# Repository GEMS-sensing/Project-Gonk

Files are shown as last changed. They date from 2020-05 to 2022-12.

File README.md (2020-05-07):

# Project-Gonk
Hardware files for battery holder systems with integrated protection 

## Notation
#### Example: 18650 1S3P 

18650 -> Model of battery used <br>
1S -> The number of cells in <b>series</b><br>
3P -> The number of cells in <b>parallel</b><br>

Output Voltage = SeriesNumber * CellVoltage<br>
Capacity = ParallelNumber * CellCapacity<br>

## Models
- [18650 1S3P](18650_1S3P)

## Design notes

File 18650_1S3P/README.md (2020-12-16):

# Project-Gonk 
### Battery: 18650 
### Configuration: 1S3P
Battery holder with integrated protection and control

# Usage
1. Toggle switch to "<b>OFF</b>" position
2. Verify battery voltage (Maximum difference between highest and lowest voltage cell should be less than <b>0.2V</b>)
3. Insert batteries into holders (<b>Note polarity markings</b>)
4. Verify polarity - if any of the <b>red indicator lamps</b> are lit, <b>stop!</b> Remove offending batteries and fix polarity before proceeding
5. If no red lamps are lit, connect external system to either of the <b>Vout</b> connectors (<b>observe polarity of connector!</b>)
6. Toggle switch to "<b>ON</b>" position when ready to activate 

# Repo Roadmap
#### [Documents](Documents/) 

General document and image storage for repo and README

#### [Hardware](Hardware/)

Current board files (Eagle), Bill of Materials (BoM), and other design documents

#### [Production](Production/)

Contains the various Gerber and pick and place files required to have the Printed Circuit Boards (PCBs) manufactured or populated 

## Overview
* **Type:** Power
* **Interfaces:** Power
* **Release Version:** v0.1

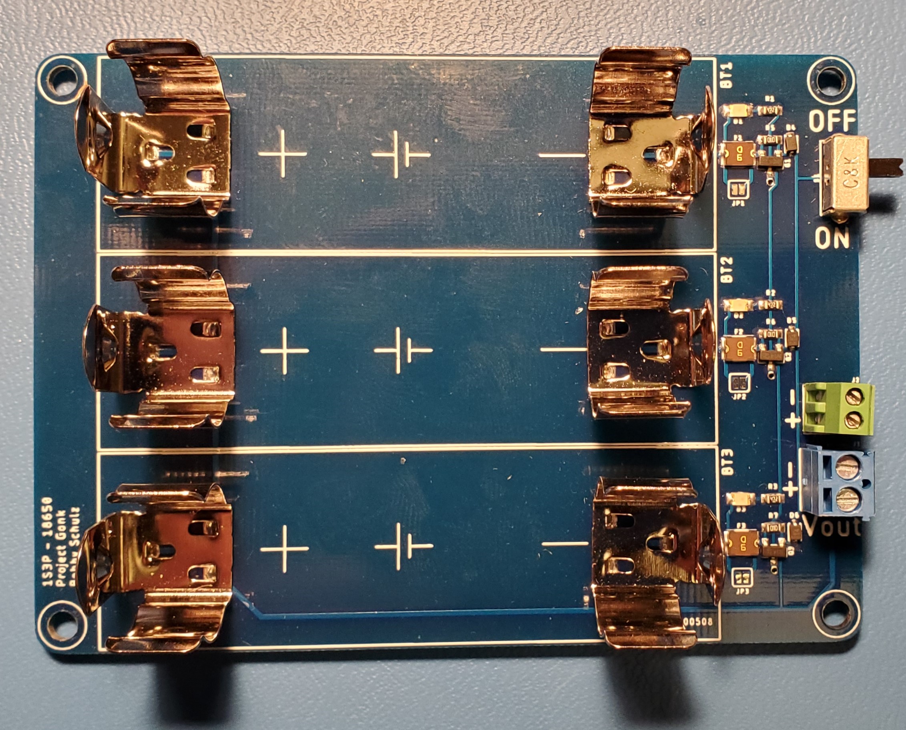
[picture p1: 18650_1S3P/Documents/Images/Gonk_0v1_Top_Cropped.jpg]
Gonk 18650 Parallel v0.1 - Top


<!-- ![Gonk 18650 Parallel v0.1 - Top](Documents/Images/Gonk_0v1_Top.jpg) -->

<!-- ![Gonk 18650 Parallel v0.1 - Bottom](Documents/Images/Gonk_0v1_Bottom.jpg) -->

## Features
### On-Board
* Power switch
* Reverse battery indication
* Poly fuse per battery

### Interface

## Specifications
* **Output Current (Max Constant):** 5.25A
* **Current Per Battery (Max Constant):** 1.75A

## Jumper Settings 

**Configuration Jumpers**
| Jumper | Purpose | Open | Closed | Default | 
| --- | --- | --- | --- | ----- |
| `JP1` | Bypass poly fuse on battery 1 | Short Circuit Protection Enabled | Short Circuit Protection Disabled | Open |  
| `JP2` | Bypass poly fuse on battery 2 | Short Circuit Protection Enabled | Short Circuit Protection Disabled | Open |
| `JP3` | Bypass poly fuse on battery 3 | Short Circuit Protection Enabled | Short Circuit Protection Disabled | Open | 

## Known Issues/Errata

#### None!

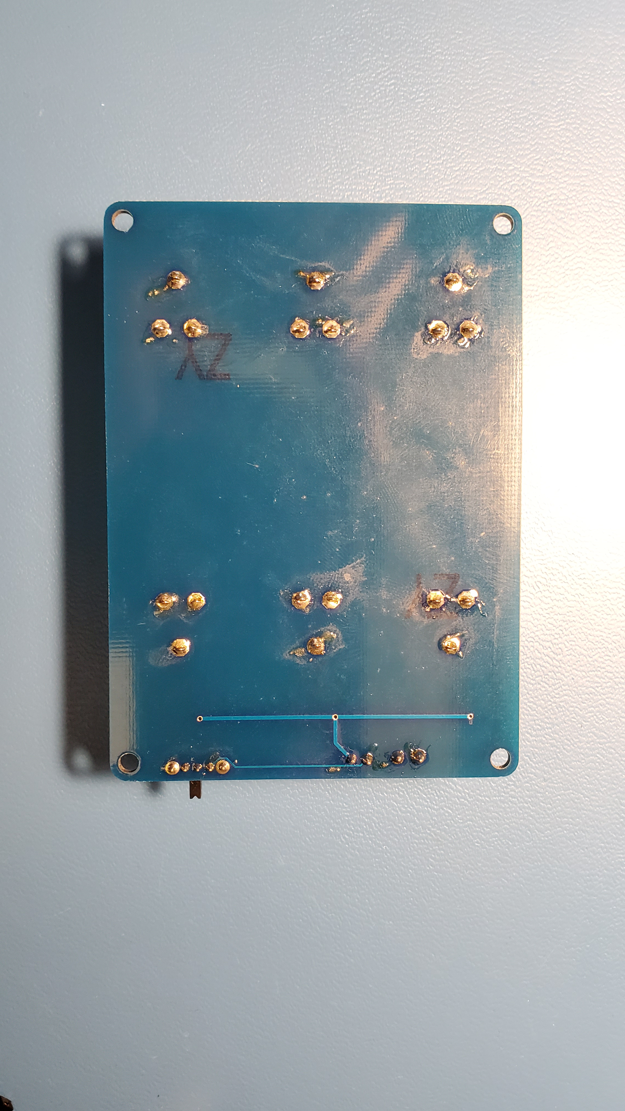
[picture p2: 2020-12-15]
18650_1S3P/Documents/Images/Gonk_0v1_Bottom.jpg

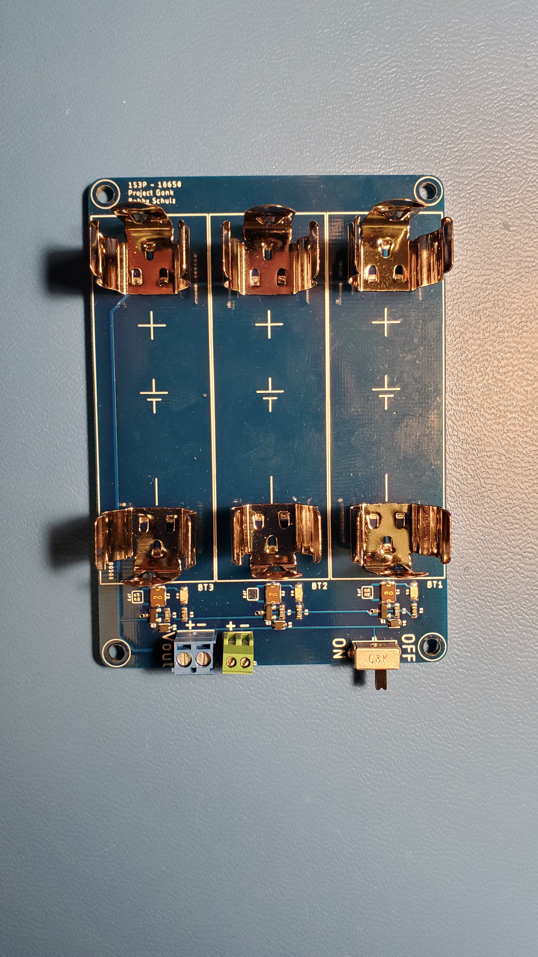
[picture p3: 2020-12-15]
18650_1S3P/Documents/Images/Gonk_0v1_Top.jpg

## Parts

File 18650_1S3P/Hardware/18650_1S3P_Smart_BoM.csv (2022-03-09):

Qty | Value | Device | Package | Parts | Description | DIGIKEY | DISP | MF | MOUSER | MPN | VALUE_PART
4 |  | MOUNTING_HOLE2_NP | 2_56 | H1, H2, H3, H4 | Genaric Mechanical Mounting Hole | DNP |  | N/A |  | DNP
2 | 0.1uF | C-EU0.1UFC0603 | C0603 | C4, C7 | CAPACITOR, European symbol | 490-6051-1-ND |  | Murata |  | GCM188R71E104KA57D
1 | 0.47uF | C-EU0.47UFC0603 | C0603 | C5 | CAPACITOR, European symbol | 1276-2083-1-ND |  | Samsung |  | CL10B474KA8NNNC
6 | 100R | R-EU_100R0603 | R0603 | R1, R5, R7, R11, R13, R17 | RESISTOR, European symbol | 311-100HRCT-ND |  | Yageo |  | RC0603FR-07100RL | 100
2 | 100k | R-EU_100KR0603 | R0603 | R24, R25 | RESISTOR, European symbol | 311-100KHRCT-ND |  | Yageo |  | RC0603FR-07100KL | 100k
1 | 10k | R-EU_10KR0603 | R0603 | R28 | RESISTOR, European symbol | 311-10.0KHRCT-ND |  | Yageo |  | RC0603FR-0710KL | 10k
1 | 10m | R-EU_0.01R0805 | R0805 | R19 | RESISTOR, European symbol | CRF0805-FZ-R010ELFCT-ND |  | Bourns |  | CRF0805-FZ-R010ELF
3 | 186501042P_NOSILK | 186501042P_NOSILK | BATT_1042P_NOSILK | BT1, BT2, BT3 | Battery Holder 18650 form factor Variant for with or without circuit protection (length varries depending on this) | 36-1042P-ND |  | Keystone |  | 1042P
4 | 1M | R-EU_1MR0603 | R0603 | R27, R29, R30, R31 | RESISTOR, European symbol | P1.00MHCT-ND |  | Panasonic |  | ERJ-3EKF1004V | 1M
4 | 1k | R-EU_1KR0603 | R0603 | R3, R9, R15, R32 | RESISTOR, European symbol | 311-1KLDCT-ND |  | Yageo |  | AC0603FR-071KL | 1k
4 | 1uF | C-EU1UFC0603 | C0603 | C1, C2, C3, C6 | CAPACITOR, European symbol | 587-1251-1-ND |  | Yaiyo Yuden |  | EMK107BJ105KA-T
3 | 20R | R-EU_20R0603 | R0603 | R4, R10, R16 | RESISTOR, European symbol | 311-20.0HRCT-ND |  | Yageo |  | RC0603FR-0720RL | 20
3 | 2m | R-EU_0.002R0805 | R0805 | R6, R12, R18 | RESISTOR, European symbol | RHM.002AJCT-ND |  | Rohm |  | PMR10EZPFV2L00
4 | 30R | R-EU_30R0603 | R0603 | R20, R21, R22, R23 | RESISTOR, European symbol | 311-30.0HRCT-ND |  | Yageo |  | RC0603FR-0730RL | 30
4 | 330R | R-EU_330R0603 | R0603 | R2, R8, R14, R26 | RESISTOR, European symbol | 311-330HRCT-ND |  | Yageo |  | RC0603FR-07330RL | 330
3 | BQ2980RUG | BQ2980RUG | RUG_S-PQFP-N8 | U1, U2, U3 | BQ2980 - Voltage, Current, Temperature Protectors with an Integrated High-Side NFET (BMS) | 296-47578-1-ND |  | TI | 595-BQ298000RUGT | BQ298000RUGT
3 | BUTTON6X6_TH | BUTTON6X6_TH | SWITCH_6MM_TH | S1, S2, S3 | Genaric SPST Push button | 450-1650-ND |  | TE Connectivity |  | 1825910-6
1 | CONN_3MICROFIT_RT | CONN_3MICROFIT_RT | 1X3_MICROFIT_RT | J1 | Genaric 3 terminal header | WM1861-ND |  | Molex |  | 0436500300
3 | DIODE_SCHOTTKYSOD-323 | DIODE_SCHOTTKYSOD-323 | SOD323-R | D1, D2, D3 | Generic Shottky Diode | BAT54WS-FDICT-ND |  | Diodes Inc |  | BAT54WS-7-F
1 | GEMS_POWER_PLUGOUTPUT | GEMS_POWER_PLUGOUTPUT | 2X3_MICROFIT_RT | J2 | Power Plug For GEMS Based SystemsBoth Input and Output versions | WM1815-ND | Output | Molex |  | 0430450600
5 | LED1206_BOTTOM | LED1206_BOTTOM | LED_1206_BOTTOM | D4, D5, D6, D7, D8 | Genaric LED
1 | MAX17263 | MAX17263 | DFN_14_3X3 | U4 | MAX17263 - Single/Multi-Cell Fuel Gauge with Integrated LED Control | 175-MAX17263LETD+TCT-ND |  | Maxim |  | MAX17263LETD+T
6 | MOSFET-NCH-AON7522E | MOSFET-NCH-AON7522E | DFN3X3A_8L_EP1_P | Q1, Q2, Q3, Q4, Q5, Q6 | N-channel MOSFETs | 785-1505-1-ND |  | Alpha & Omega |  | AON7522E
2 | MOSFET_PCH-DMP2008 | MOSFET_PCH-DMP2008 | POWERDI3333-8 | Q7, Q8 | P-channel MOSFETs
1 | SPDTOS1020_RT | SPDTOS1020_RT | OS102011MA1QN1 | S4 | Genaric SPDT switch | CKN9559-ND |  | C&K |  | OS102011MA1QN1
1 | TLV3691DCK | TLV3691DCK | DCK_R-PDSO-G5 | U5 | TLV3691 - Nanopower Analog Comparator | 296-37910-1-ND |  | TI |  | TLV3691IDCKR

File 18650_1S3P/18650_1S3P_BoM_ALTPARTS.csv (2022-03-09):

Qty | Value | Device | Package | Parts | Description | DIGIKEY | MF | MPN | VALUE | VALUE_PART
1 |  | CONN_022.54_SCREW_ROUND | 1X02_2.54_SCREWTERM_ROUND | J2 | Genaric 2 terminal header | ED10561-ND | OnShore | OSTVN02A150
1 |  | CONN_023.5MM_ROUND_RESTRICT | SCREWTERMINAL-3.5MM-2_ROUND_RESTRICT | J1 | Genaric 2 terminal header | ED2635-ND | On Shore | OSTTE020161
4 |  | MOUNTING_HOLE4_NP | 4_40 | H1, H2, H3, H4 | Genaric Mechanical Mounting Hole | DNP | N/A | DNP
3 | 1.75A | PPTC1.75A1210 | 1210_BOURNS | F1, F2, F3 | Bel Fuse PPTC | MF-USMF175X-2CT-ND | Bourns | MF-USMF175X-2
3 | 100k | R-EU_100KR0603 | R0603 | R5, R6, R7 | RESISTOR, European symbol | 311-100KHRCT-ND | Yageo | RC0603FR-07100KL |  | 100k
3 | 18650NO_PROTEC | 18650NO_PROTEC | BATT_18650_CLIP | BT1, BT2, BT3 | Battery Holder 18650 form factor Variant for with or without circuit protection (length varries depending on this) | 36-54-ND | Keystone | 54
3 | BAS16WX | DIODESOD-323 | SOD323-R | D4, D5, D6 | Genaric Diode | BAS16WXTPMSDKR-ND | Micro Semi | BAS16WX-TP
3 | 4.7k | R-EU_4.7KR0603 | R0603 | R1, R2, R3 | RESISTOR, European symbol | 311-4.70KHRCT-ND | Yageo | RC0603FR-074K7L |  | 4.7k
3 | DMG3406 | MOSFET-NCH-DMG3406L | SOT23-3 | Q1, Q2, Q3 | N-channel MOSFETs | DMG3406L-13DICT-ND | Diodes Incorporated | DMG3406L-13 | DMG3406
3 | JUMPER-SMT_2_NO_SILK | JUMPER-SMT_2_NO_SILK | SMT-JUMPER_2_NO_SILK | JP1, JP2, JP3 | Normally open jumper | N/A | N/A | DNP
3 | LED0805 | LED0805 | LED_0805 | D1, D2, D3 | Genaric LED | 1497-XZMDK54W-4DKR-ND | SunLED | XZMDK54W-4
1 | SPDTOS1020_RT | SPDTOS1020_RT | OS102011MA1QN1 | S1 | Genaric SPDT switch | CKN9559-ND | C&K | OS102011MA1QN1

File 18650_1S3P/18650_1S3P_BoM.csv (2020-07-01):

Qty | Value | Device | Package | Parts | Description | DIGIKEY | MF | MPN | VALUE | VALUE_PART
1 |  | CONN_022.54_SCREW_ROUND | 1X02_2.54_SCREWTERM_ROUND | J2 | Genaric 2 terminal header | ED10561-ND | OnShore | OSTVN02A150
1 |  | CONN_023.5MM_ROUND_RESTRICT | SCREWTERMINAL-3.5MM-2_ROUND_RESTRICT | J1 | Genaric 2 terminal header | ED2635-ND | On Shore | OSTTE020161
4 |  | MOUNTING_HOLE4_NP | 4_40 | H1, H2, H3, H4 | Genaric Mechanical Mounting Hole | DNP | N/A | DNP
3 | 1.75A | PPTC1.75A1210 | 1210_BOURNS | F1, F2, F3 | Bel Fuse PPTC | MF-USMF175X-2CT-ND | Bourns | MF-USMF175X-2
3 | 100k | R-EU_100KR0603 | R0603 | R5, R6, R7 | RESISTOR, European symbol | 311-100KHRCT-ND | Yageo | RC0603FR-07100KL |  | 100k
3 | 18650NO_PROTEC | 18650NO_PROTEC | BATT_18650_CLIP | BT1, BT2, BT3 | Battery Holder 18650 form factor Variant for with or without circuit protection (length varries depending on this) | 36-54-ND | Keystone | 54
3 | 1N4148 | DIODESOD-323 | SOD323-R | D4, D5, D6 | Genaric Diode | 1N4148WS-FDICT-ND | Diodes Inc | 1N4148WS-7-F
3 | 4.7k | R-EU_4.7KR0603 | R0603 | R1, R2, R3 | RESISTOR, European symbol | 311-4.70KHRCT-ND | Yageo | RC0603FR-074K7L |  | 4.7k
3 | DMG3404 | MOSFET-NCH-DMG3404L | SOT23-3 | Q1, Q2, Q3 | N-channel MOSFETs | DMG3404L-7DICT-ND | Diodes Incorporated | DMG3404L-7 | DMG3404
3 | JUMPER-SMT_2_NO_SILK | JUMPER-SMT_2_NO_SILK | SMT-JUMPER_2_NO_SILK | JP1, JP2, JP3 | Normally open jumper
3 | LED0805 | LED0805 | LED_0805 | D1, D2, D3 | Genaric LED | 475-1278-1-ND | OSRAM | LS R976-NR-1
1 | SPDTOS1020_RT | SPDTOS1020_RT | OS102011MA1QN1 | S1 | Genaric SPDT switch | CKN9559-ND | C&K | OS102011MA1QN1

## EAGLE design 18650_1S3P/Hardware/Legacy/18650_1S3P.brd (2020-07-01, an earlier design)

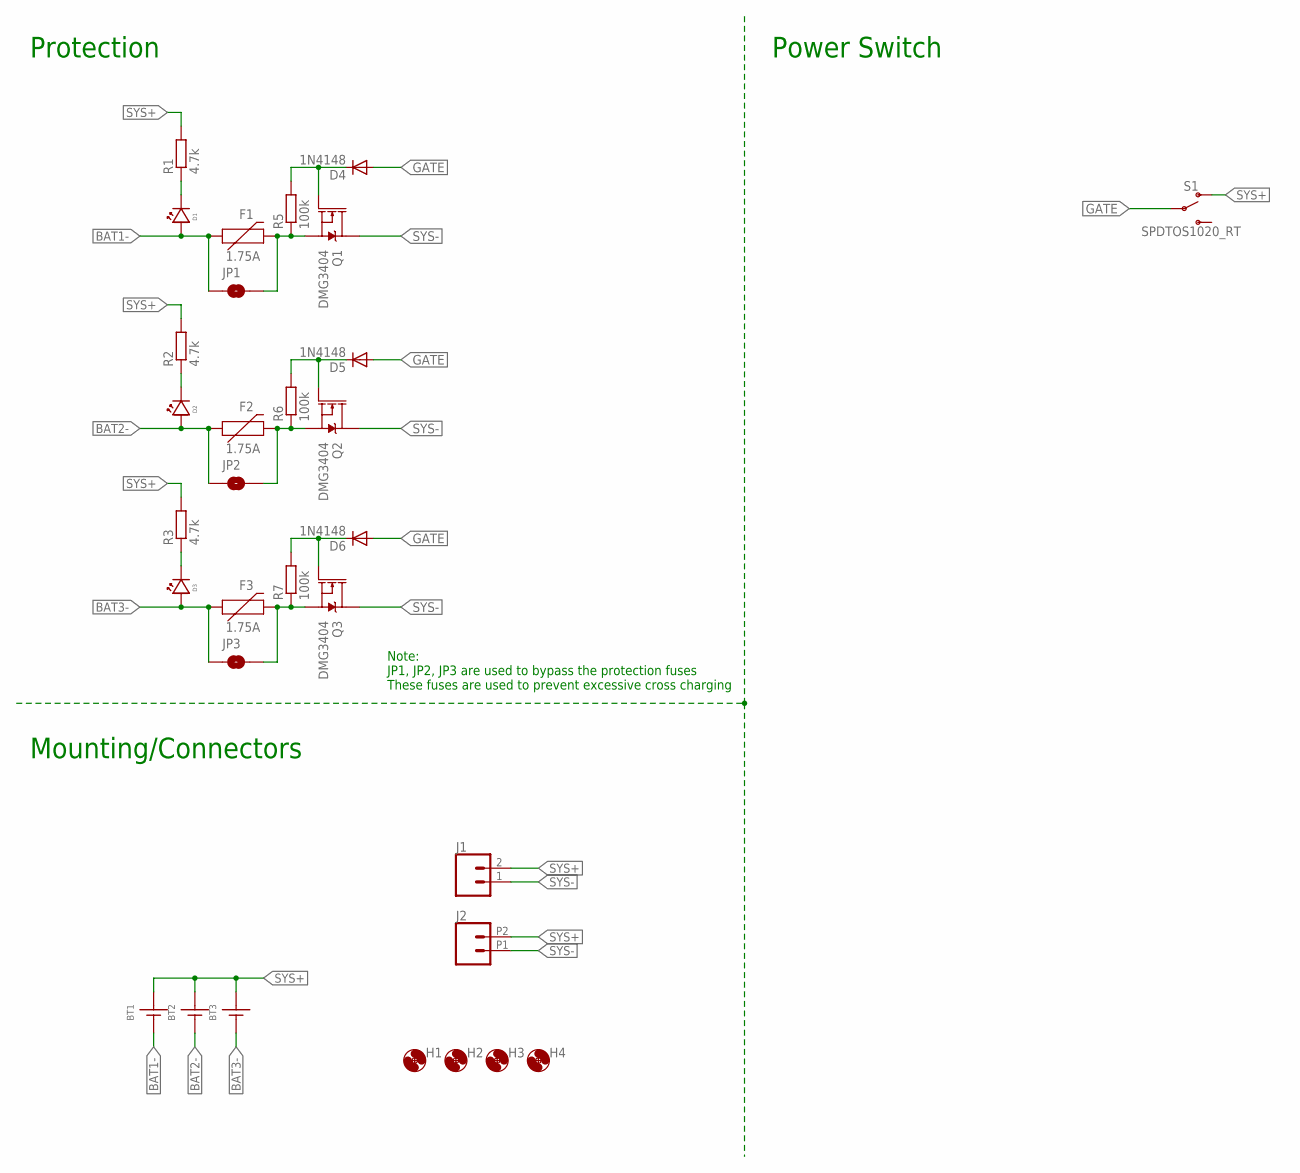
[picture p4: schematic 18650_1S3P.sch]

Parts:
BT1, BT2, BT3: 18650NO_PROTEC; BATT_18650_CLIP
D1, D2, D3: LED0805; LED_0805; MPN LS R976-NR-1; DIGIKEY 475-1278-1-ND
D4, D5, D6: 1N4148; SOD323-R; MPN 1N4148WS-7-F; DIGIKEY 1N4148WS-FDICT-ND
F1, F2, F3: 1.75A; 1210_BOURNS
H1, H2, H3, H4: MOUNTING_HOLE4_NP; 4_40
J1: CONN_023.5MM_ROUND_RESTRICT; SCREWTERMINAL-3.5MM-2_ROUND_RESTRICT
J2: CONN_022.54_SCREW_ROUND; 1X02_2.54_SCREWTERM_ROUND
JP1, JP2, JP3: JUMPER-SMT_2_NO_SILK; SMT-JUMPER_2_NO_SILK
Q1, Q2, Q3: DMG3404; SOT23-3
R1, R2, R3: 4.7k; R0603
R5, R6, R7: 100k; R0603
S1: SPDTOS1020_RT; OS102011MA1QN1

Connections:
BAT1-: BT1.BATT-@1 (-), BT1.BATT-@2 (-), BT1.BATT-@3 (-), D1.ANODE, F1.1, JP1.1
BAT2-: BT2.BATT-@1 (-), BT2.BATT-@2 (-), BT2.BATT-@3 (-), D2.ANODE, F2.1, JP2.1
BAT3-: BT3.BATT-@1 (-), BT3.BATT-@2 (-), BT3.BATT-@3 (-), D3.ANODE, F3.1, JP3.1
GATE: D4.A, D5.A, D6.A, S1.2
unnamed: D2.CATHODE, R2.1
unnamed: D1.CATHODE, R1.1
unnamed: F1.2, JP1.2, Q1.2 (S), R5.1
unnamed: F2.2, JP2.2, Q2.2 (S), R6.1
unnamed: D3.CATHODE, R3.1
unnamed: F3.2, JP3.2, Q3.2 (S), R7.1
unnamed: D5.C, Q2.1 (G), R6.2
unnamed: D4.C, Q1.1 (G), R5.2
unnamed: D6.C, Q3.1 (G), R7.2
SYS+: BT1.BATT+@1 (+), BT1.BATT+@2 (+), BT1.BATT+@3 (+), BT2.BATT+@1 (+), BT2.BATT+@2 (+), BT2.BATT+@3 (+), BT3.BATT+@1 (+), BT3.BATT+@2 (+), BT3.BATT+@3 (+), J1.2, J2.P2 (2), R1.2, R2.2, R3.2, S1.1 (O)
SYS-: J1.1, J2.P1 (1), Q1.3 (D), Q2.3 (D), Q3.3 (D)

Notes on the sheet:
Mounting/Connectors
Protection
Note: JP1, JP2, JP3 are used to bypass the protection fuses These fuses are used to prevent excessive cross charging
Power Switch

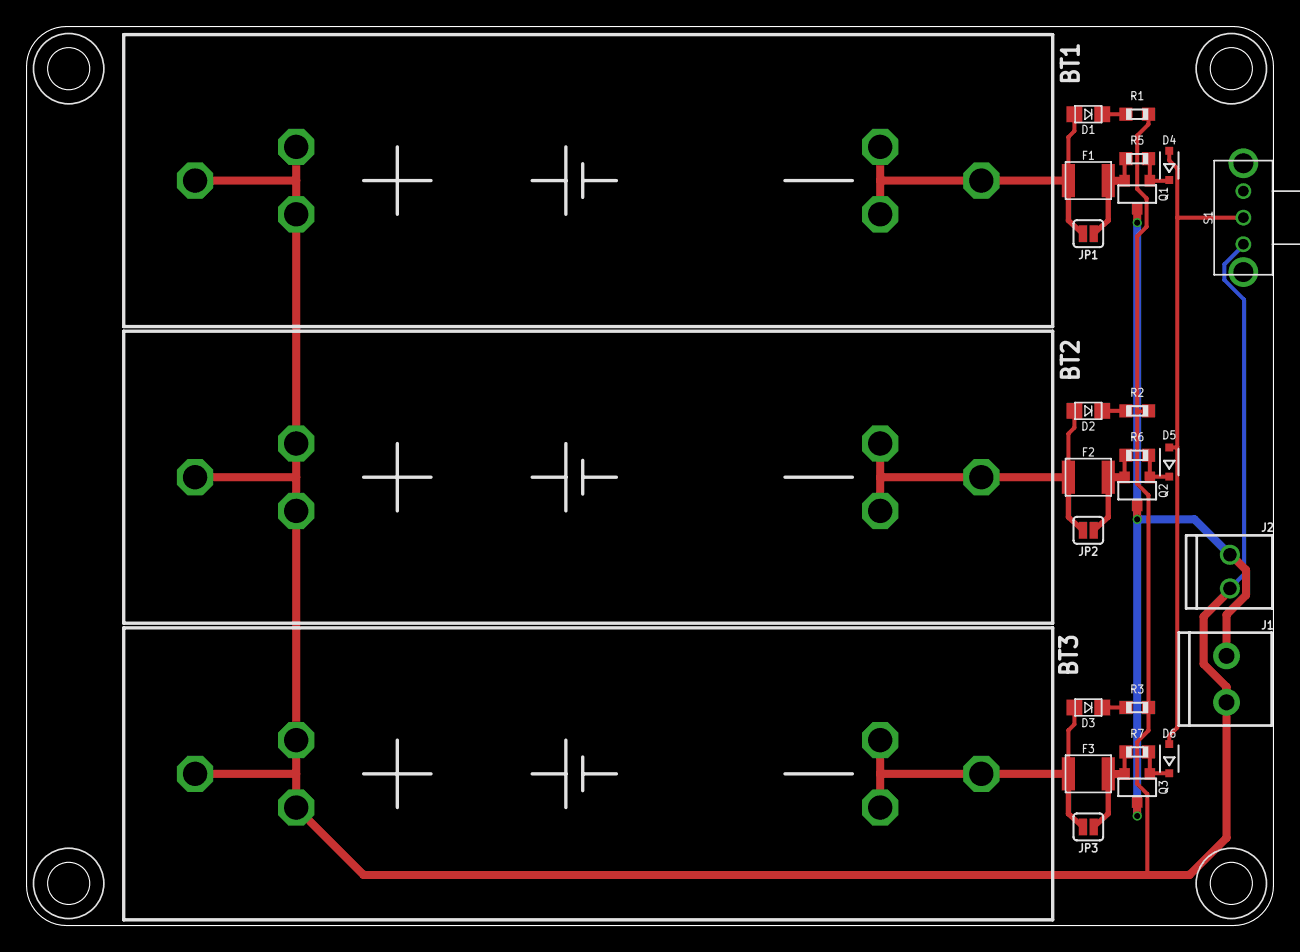
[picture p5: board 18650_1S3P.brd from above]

Board: 2 copper layers, 94.0 x 67.7 mm, 31 parts (0 on the bottom side), 15 nets.

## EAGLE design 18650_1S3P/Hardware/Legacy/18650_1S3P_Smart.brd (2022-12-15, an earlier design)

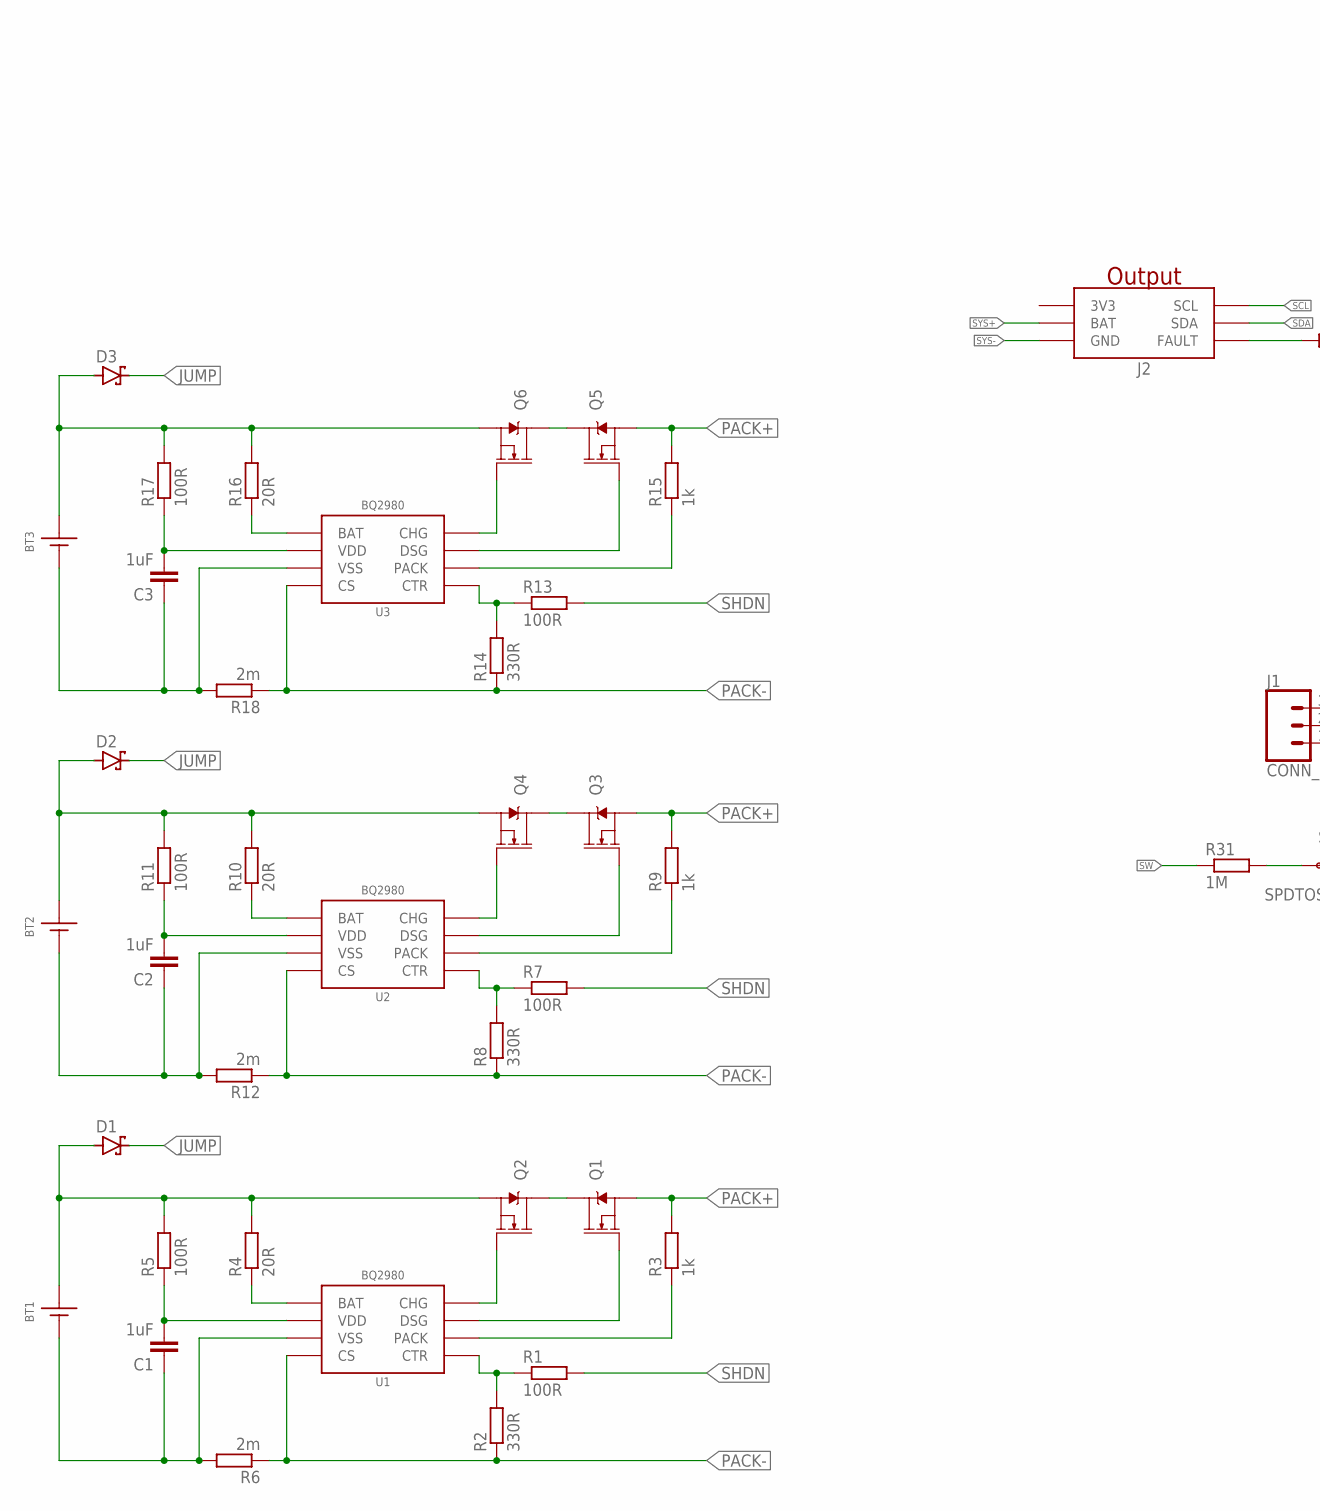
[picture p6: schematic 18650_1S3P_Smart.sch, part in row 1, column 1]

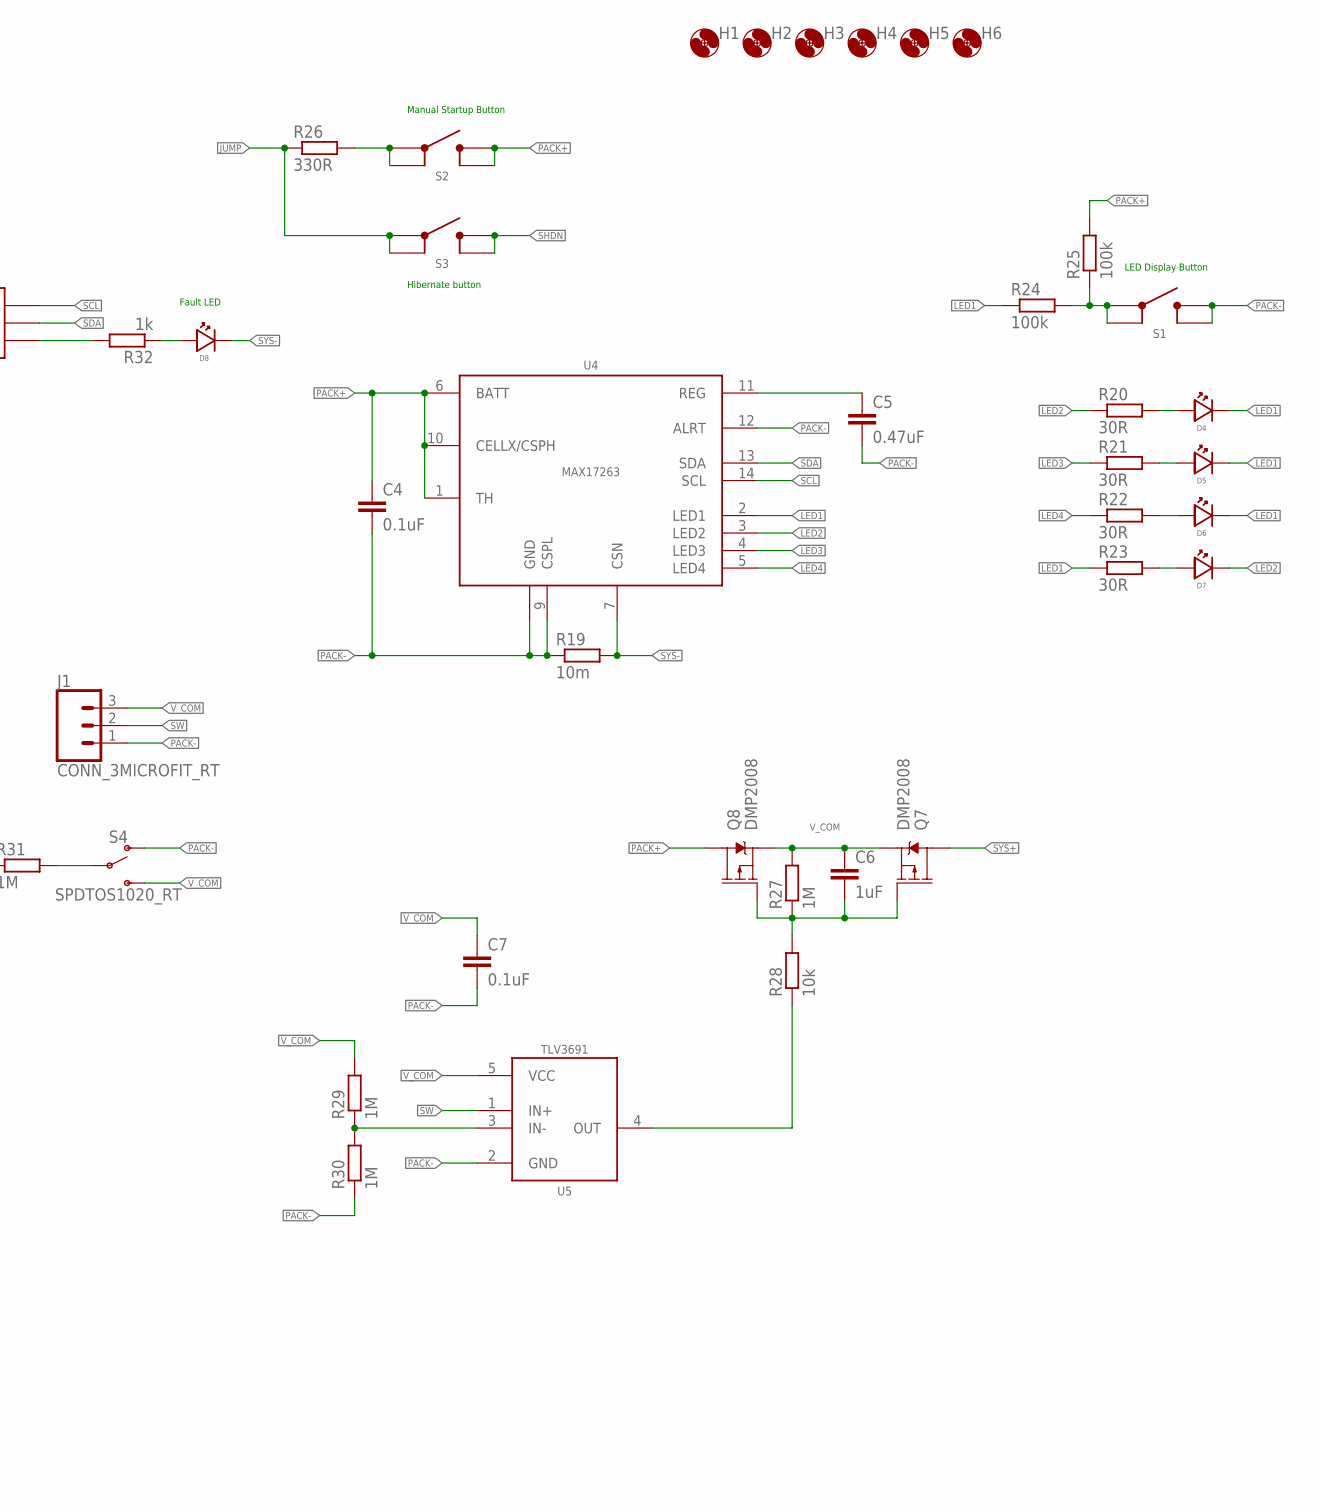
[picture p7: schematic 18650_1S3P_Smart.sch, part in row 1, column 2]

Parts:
BT1, BT2, BT3: 186501042P_NOSILK; BATT_1042P_NOSILK
C1, C2, C3, C6: 1uF; C0603
C4, C7: 0.1uF; C0603
C5: 0.47uF; C0603
D1, D2, D3: DIODE_SCHOTTKYSOD-323; SOD323-R; MPN BAT54WS-7-F; DIGIKEY BAT54WS-FDICT-ND
D4, D5, D6, D7: LED1206_BOTTOM; LED_1206_BOTTOM; MPN LTST-C230KGKT; DIGIKEY 160-1456-1-ND
D8: LED1206_BOTTOM; LED_1206_BOTTOM; MPN LTST-C230KRKT; DIGIKEY 160-1457-1-ND
H1, H2, H3, H4, H5, H6: MOUNTING_HOLE4_NP; 4_40
J1: CONN_3MICROFIT_RT; 1X3_MICROFIT_RT
J2: GEMS_POWER_PLUGOUTPUT; 2X3_MICROFIT_RT
Q1, Q2, Q3, Q4, Q5, Q6: AON7522E; DFN3X3A_8L_EP1_P
Q7, Q8: DMP2008; POWERDI3333-8
R1, R5, R7, R11, R13, R17: 100R; R0603
R2, R8, R14, R26: 330R; R0603
R3, R9, R15, R32: 1k; R0603
R4, R10, R16: 20R; R0603
R6, R12, R18: 2m; R0805
R19: 10m; R0805
R20, R21, R22, R23: 30R; R0603
R24, R25: 100k; R0603
R27, R29, R30, R31: 1M; R0603
R28: 10k; R0603
S1, S2, S3: BUTTON6X6_TH; SWITCH_6MM_TH
S4: SPDTOS1020_RT; OS102011MA1QN1
U1, U2, U3: BQ2980RUG; RUG_S-PQFP-N8
U4: MAX17263; DFN_14_3X3
U5: TLV3691DCK; DCK_R-PDSO-G5

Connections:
3V3: J2.5 (3V3)
JUMP: D1.C, D2.C, D3.C, R26.1, S3.1, S3.2
LED1: D4.CATHODE, D5.CATHODE, D6.CATHODE, R23.1, R24.1, U4.2 (LED1)
LED2: D7.CATHODE, R20.1, U4.3 (LED2)
LED3: R21.1, U4.4 (LED3)
LED4: R22.1, U4.5 (LED4)
unnamed: Q1.D, Q2.D
unnamed: Q2.G, U1.8 (CHG)
unnamed: Q1.G, U1.7 (DSG)
unnamed: R1.1, R2.2, U1.5 (CTR)
unnamed: R3.1, U1.6 (PACK)
unnamed: BT1.BATT+ (+), D1.A, Q2.S@1 (S), Q2.S@2 (S), Q2.S@3 (S), R4.2, R5.2
unnamed: C1.2, R5.1, U1.2 (VDD)
unnamed: R4.1, U1.1 (BAT)
unnamed: BT1.BATT- (-), C1.1, R6.2, U1.3 (VSS)
unnamed: Q3.D, Q4.D
unnamed: Q4.G, U2.8 (CHG)
unnamed: Q3.G, U2.7 (DSG)
unnamed: R9.1, U2.6 (PACK)
unnamed: R7.1, R8.2, U2.5 (CTR)
unnamed: BT2.BATT+ (+), D2.A, Q4.S@1 (S), Q4.S@2 (S), Q4.S@3 (S), R10.2, R11.2
unnamed: C2.2, R11.1, U2.2 (VDD)
unnamed: R10.1, U2.1 (BAT)
unnamed: BT2.BATT- (-), C2.1, R12.2, U2.3 (VSS)
unnamed: Q5.D, Q6.D
unnamed: Q6.G, U3.8 (CHG)
unnamed: Q5.G, U3.7 (DSG)
unnamed: R15.1, U3.6 (PACK)
unnamed: R13.1, R14.2, U3.5 (CTR)
unnamed: BT3.BATT+ (+), D3.A, Q6.S@1 (S), Q6.S@2 (S), Q6.S@3 (S), R16.2, R17.2
unnamed: C3.2, R17.1, U3.2 (VDD)
unnamed: R16.1, U3.1 (BAT)
unnamed: BT3.BATT- (-), C3.1, R18.2, U3.3 (VSS)
unnamed: D4.ANODE, R20.2
unnamed: D5.ANODE, R21.2
unnamed: D6.ANODE, R22.2
unnamed: D7.ANODE, R23.2
unnamed: R24.2, R25.1, S1.1, S1.2
unnamed: C5.1, U4.11 (REG)
unnamed: R26.2, S2.1, S2.2
unnamed: R31.2, S4.2
unnamed: C6.2, Q7.4 (G), Q8.4 (G), R27.1, R28.2
unnamed: R28.1, U5.4 (OUT)
unnamed: J2.1 (FAULT), R32.2
unnamed: R29.1, R30.2, U5.3 (IN-)
unnamed: D8.ANODE, R32.1
PACK+: C4.1, Q1.S@1 (S), Q1.S@2 (S), Q1.S@3 (S), Q3.S@1 (S), Q3.S@2 (S), Q3.S@3 (S), Q5.S@1 (S), Q5.S@2 (S), Q5.S@3 (S), Q8.EP@1 (D), Q8.EP@2 (D), Q8.EP@3 (D), Q8.EP@4 (D), Q8.EP@5 (D), R3.2, R9.2, R15.2, R25.2, S2.3, S2.4, U4.1 (TH), U4.6 (BATT), U4.10 (CELLX/CSPH)
PACK-: C4.2, C5.2, C7.2, J1.1, R2.1, R6.1, R8.1, R12.1, R14.1, R18.1, R19.1, R30.1, S1.3, S1.4, S4.1 (O), U1.4 (CS), U2.4 (CS), U3.4 (CS), U4.8 (GND), U4.9 (CSPL), U4.12 (ALRT), U4.EP (GND), U5.2 (GND)
SCL: J2.4 (SCL), U4.14 (SCL)
SDA: J2.6 (SDA), U4.13 (SDA)
SHDN: R1.2, R7.2, R13.2, S3.3, S3.4
SW: J1.2, R31.1, U5.1 (IN+)
SYS+: J2.3 (BAT), Q7.EP@1 (D), Q7.EP@2 (D), Q7.EP@3 (D), Q7.EP@4 (D), Q7.EP@5 (D)
SYS-: D8.CATHODE, J2.2 (GND), R19.2, U4.7 (CSN)
V_COM: C6.1, C7.1, J1.3, Q7.1 (S), Q7.2 (S), Q7.3 (S), Q8.1 (S), Q8.2 (S), Q8.3 (S), R27.2, R29.2, S4.3 (S), U5.5 (VCC)

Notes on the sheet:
LED Display Button
Manual Startup Button
Hibernate button
Fault LED

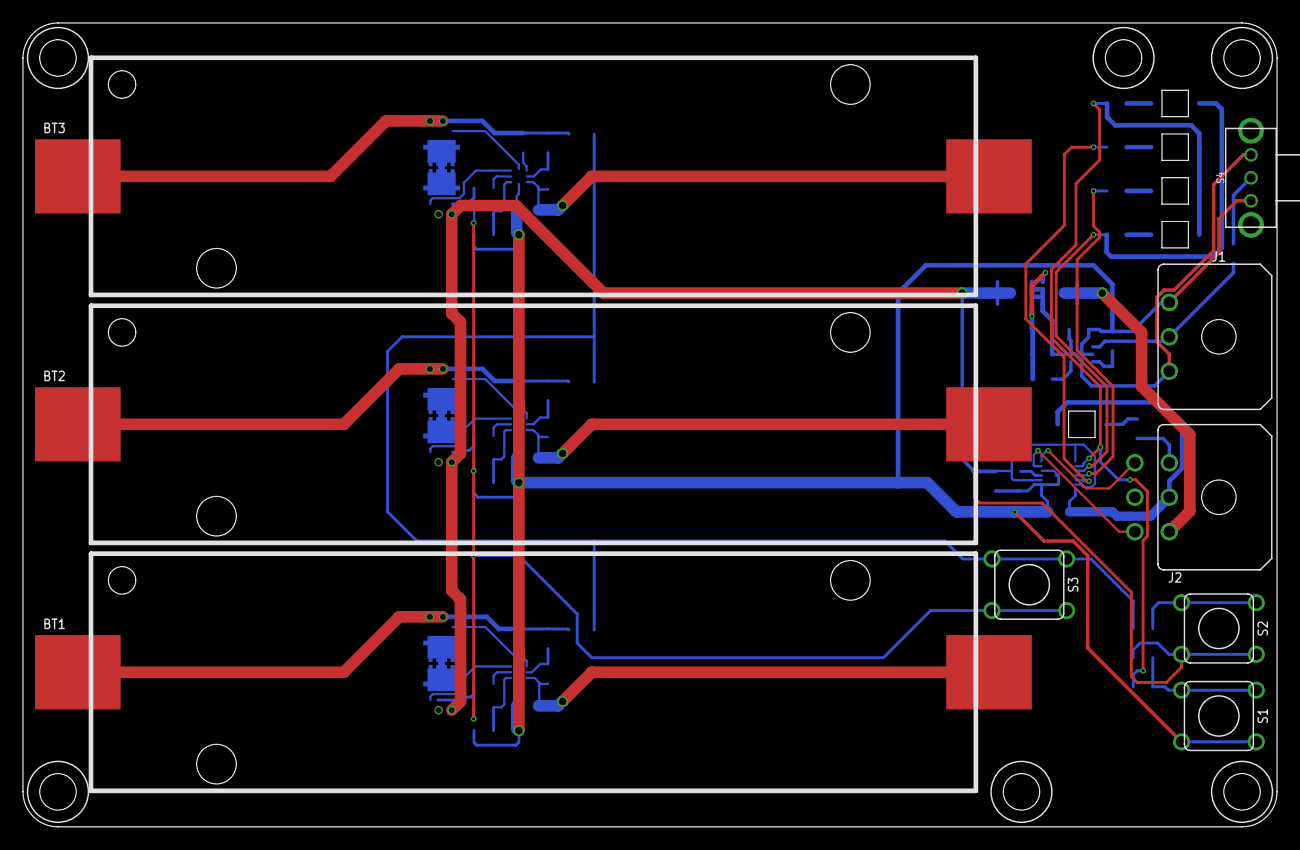
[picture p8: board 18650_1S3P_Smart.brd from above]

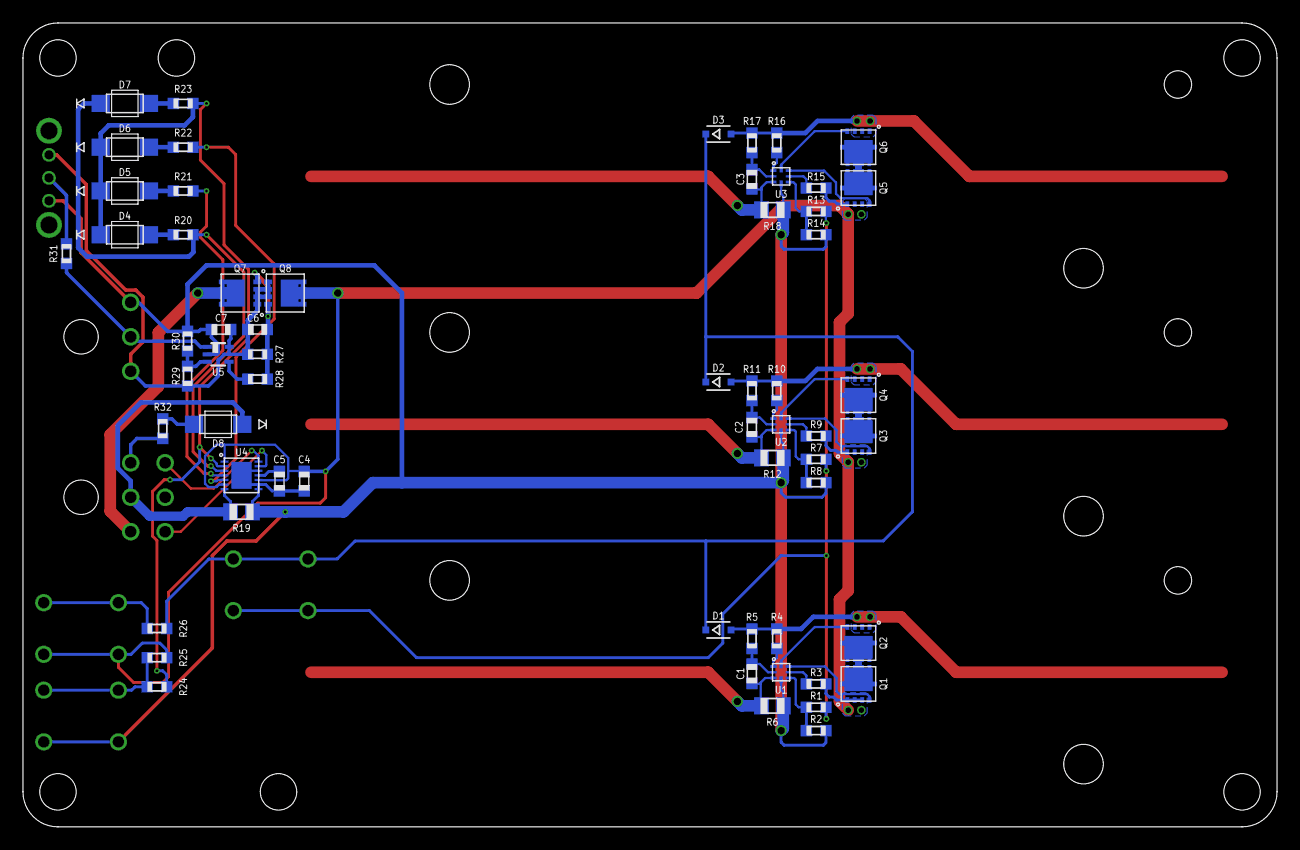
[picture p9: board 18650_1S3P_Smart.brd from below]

Board: 2 copper layers, 109.2 x 70.0 mm, 75 parts (60 on the bottom side), 54 nets.

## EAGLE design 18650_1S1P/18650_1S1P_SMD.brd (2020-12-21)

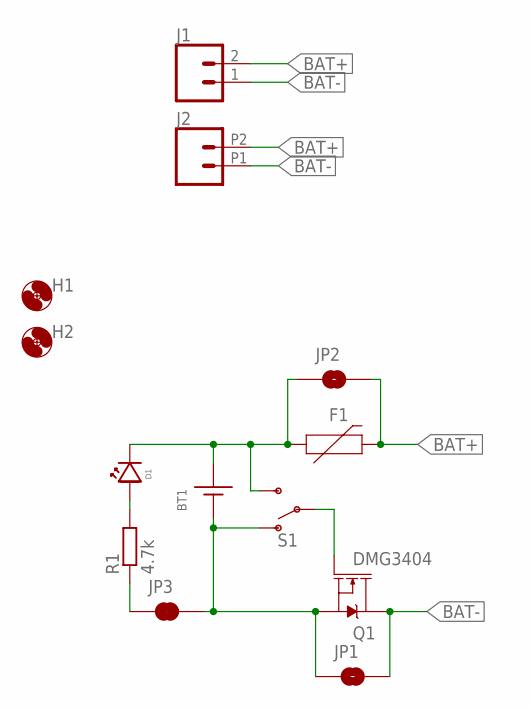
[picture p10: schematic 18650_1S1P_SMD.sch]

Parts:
BT1: 186501042P; BATT_1042P
D1: LED0603; LED_0603
F1: PPTC1.75A1210; 1210_BOURNS
H1, H2: MOUNTING_HOLE4_NP; 4_40
J1: CONN_023.5MM_ROUND_RESTRICT; SCREWTERMINAL-3.5MM-2_ROUND_RESTRICT
J2: CONN_022.54_SCREW_ROUND; 1X02_2.54_SCREWTERM_ROUND
JP1, JP2: JUMPER-SMT_2_NO_SILK; SMT-JUMPER_2_NO_SILK
JP3: JUMPER-SMT_2_NC_TRACE_SILK; SMT-JUMPER_2_NC_TRACE_SILK
Q1: DMG3404; SOT23-3
R1: 4.7k; R0603
S1: SPDTOS1020; OS102011MS2QN1

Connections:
BAT+: F1.2, J1.2, J2.P2 (2), JP2.2
BAT-: J1.1, J2.P1 (1), JP1.2, Q1.3 (D)
unnamed: BT1.BATT+ (+), D1.CATHODE, F1.1, JP2.1, S1.3 (S)
unnamed: D1.ANODE, R1.2
unnamed: Q1.1 (G), S1.2
unnamed: BT1.BATT- (-), JP1.1, JP3.2, Q1.2 (S), S1.1 (O)
unnamed: JP3.1, R1.1

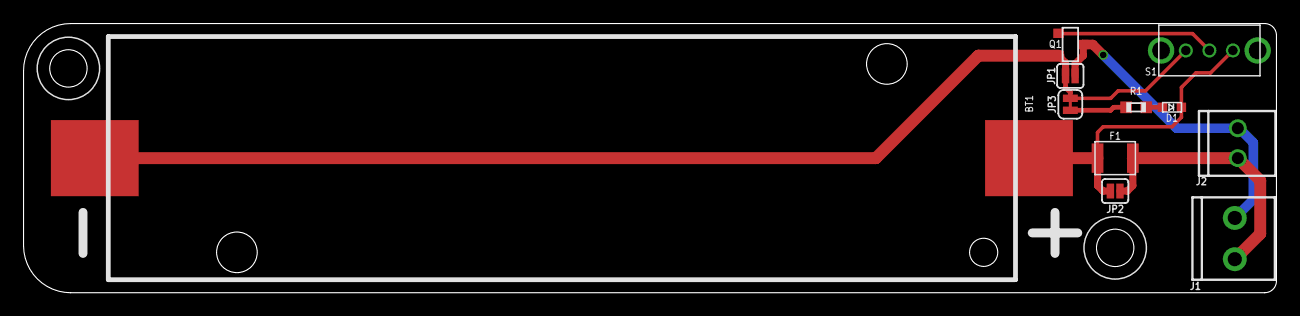
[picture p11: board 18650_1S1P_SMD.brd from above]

Board: 2 copper layers, 106.4 x 22.9 mm, 13 parts (0 on the bottom side), 7 nets.

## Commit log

2020-05-06 Initial v0.0 system
    Late stage push of the v0.0 system, updates coming after testing of prototype hardware
    [18650_1S3P.brd, 18650_1S3P.sch, 18650_1S3P_BoM.csv]
2020-05-07 Update for v0.1 system
    Updated system to v0.1, changed switching and reverse polarity protection system, ready for fab
    [18650_1S3P.brd, 18650_1S3P.sch]
2020-05-07 Added readme and changed file structure
    Added readme with use instructions for the v0.1 18650 1S3P holder as well as general readme
    [18650_1S3P.brd, 18650_1S3P.sch, 18650_1S3P_BoM.csv]
2020-07-01 Updated diode part number, new BoM
    Fixed diode part number to be correct SOD323 diode instead of SOD523 diode, regenerated BoM to reflect change
    [18650_1S3P.brd, 18650_1S3P.sch, 18650_1S3P_BoM.csv]
2020-07-01 Added DNP to mount holes
    [18650_1S3P.brd, 18650_1S3P.sch]
2020-12-15 Added additional markdown docs, changed folder structure
    Added more markdown docs, changed how the folders are structured to at least emulate the standard being used by the GEMS system
    [18650_1S3P.brd, 18650_1S3P.sch, 18650_1S3P_BoM.csv]
2020-12-21 Added 1S1P 18650 boards
    Added SMD and PTH versions of a 1S1P breakout boards for 18650s
    [18650_1S1P_PTH.brd, 18650_1S1P_PTH.sch, 18650_1S1P_SMD.brd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]
2020-12-21 Added external switch designs
    Added designs for an external switch to control a future battery board, gerbers sent to fab
    [SwitchBreakout.brd, SwitchBreakout.sch]
2021-02-20 1S3P - Smart schematic capture, very preliminary layout
    Input schematic and began rough layout process for 1S3P smart board
    [18650_1S3P_Smart.brd, 18650_1S3P_Smart.sch]
2021-02-23 Continued layout of 1S3P Smart
    Continued layout, connections made, labeling and cleanup required. Made fix to `ALERT` pin connection (had connected to `GND` erroneously vs `PACK-`)
    [18650_1S3P_Smart.brd, 18650_1S3P_Smart.sch]
2021-02-23 Layout and ref designator cleanup, ready for final verification
    Continued layout cleanup, layout should be final barring final verification
    [18650_1S3P_Smart.brd, 18650_1S3P_Smart.sch]
2022-03-09 Backlog v0.0 and v0.1 updates
    [18650_1S3P.brd, 18650_1S3P.sch, 18650_1S3P_0v1_BoM.csv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]
2022-03-09 Added 18650_1S3P_Smart v1.1
    [18650_1S3P_Smart_1v1_BoM.csv]
2022-03-09 Added 18650_1S3P_Smart v1.2 (very and normal)
    Added v1.2 updates for both systems
    [18650_1S3P_Smart_VertCon.brd, 18650_1S3P_Smart_VertCon.sch, 18650_1S3P_Smart_VertCon_1v2_BoM.csv]
2022-03-09 Updated to use non-polarized battery holder
    [18650_1S3P_Smart_VertCon_1v2_BoM.csv]
2022-12-15 Changed folder structure to include legacy aspects
    Also changed 1042P to 1042 to match manufactured version
    [18650_1S3P.brd, 18650_1S3P.sch, 18650_1S3P_0v1_BoM.csv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]

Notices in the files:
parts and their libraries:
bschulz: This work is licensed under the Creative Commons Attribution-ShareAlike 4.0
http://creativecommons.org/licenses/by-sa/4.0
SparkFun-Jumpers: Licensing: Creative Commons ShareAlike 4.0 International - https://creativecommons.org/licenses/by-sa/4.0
